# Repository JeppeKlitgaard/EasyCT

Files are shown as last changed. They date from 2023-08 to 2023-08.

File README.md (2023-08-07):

# EasyCT

## Terminology

- Burden Resistor: Also known as *sampling resistor*

## Supported Inputs

EasyCT supports most current-mode current transformers
(that is, current transformers without a built-in burden resistor).
These will have their outputs listed as currents (typically $\textrm{mA}$ or $\textrm{A}$),
__not__ voltages ($\textrm{mV, V}$) 

Additionally the PCB footprint has support for the following transformers:
- Three Terminal Jacks (known as TRS, AUX, XLR)
  - [YHDC-SCT013-000](https://www.poweruc.pl/collections/split-core-current-transformers2/products/split-core-current-transformer-sct013-rated-input-5a-100a)
- 2-Wire
  - PZCT10020 (generally PZCT-XXXXX, etc)
  - DLXQ26-XXXX
- ZMCT-style
  - ZMCT103C
  - ZMCT118F

## Supported Configurations

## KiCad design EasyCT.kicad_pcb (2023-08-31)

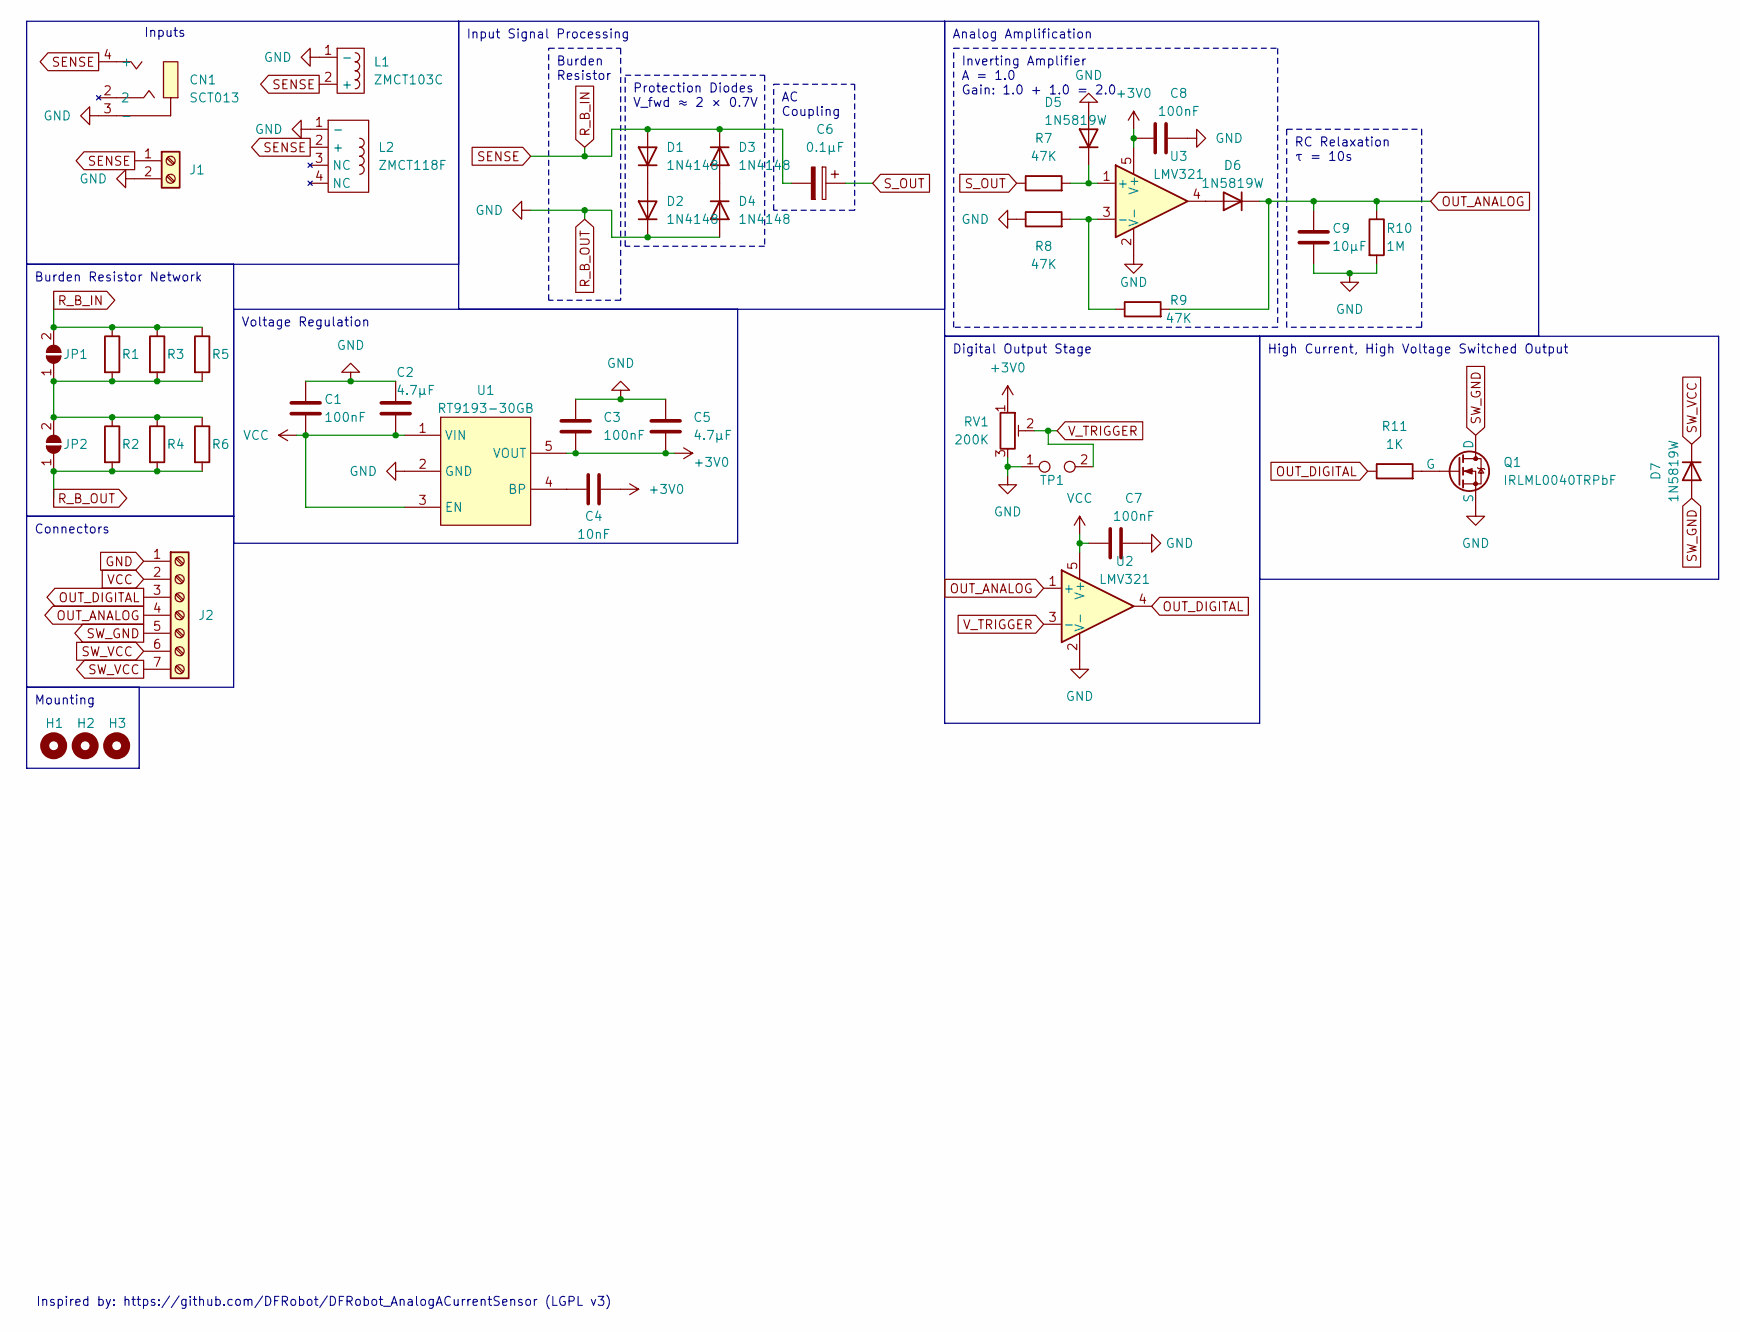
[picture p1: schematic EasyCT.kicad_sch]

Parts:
C1, C3, C7, C8: 100nF; C_0805_2012Metric
C2, C5: 4.7μF; C_0805_2012Metric
C4: 10nF; C_0805_2012Metric
C6: 0.1μF; C_0805_2012Metric
C9: 10μF; C_0805_2012Metric
CN1: SCT013; AUDIO-TH_HOOYA_PJ-320
D1, D2, D3, D4: 1N4148; D_SOD-123
D5, D6, D7: 1N5819W; D_SOD-323
H1, H2, H3: MountingHole; MountingHole_3.2mm_M3
J1: Screw_Terminal_01x02; CONN-TH_XY308-2.54-2P
J2: Screw_Terminal_01x07; CONN-TH_XY308-2.54-7P
JP1, JP2: SolderJumper_2_Open; SolderJumper-2_P1.3mm_Open_TrianglePad1.0x1.5mm
L1: ZMCT103C; Current_Transformer_CT_ZMCT103C
L2: ZMCT118F; XFMR-TH_ZMCT118F
Q1: IRLML0040TRPbF; SOT-23
R1, R2, R3, R4, R5, R6: R; R_Axial_DIN0207_L6.3mm_D2.5mm_P7.62mm_Horizontal
R7, R8, R9: 47K; R_0805_2012Metric
R10: 1M; R_0805_2012Metric
R11: 1K; R_0805_2012Metric
RV1: 200K; Potentiometer_Bourns_3296W_Vertical
TP1: TestPoint_2Pole; TestPoint_2Pads_Pitch5.08mm_Drill1.3mm
U1: RT9193-30GB; SOT-23-5_L3.0-W1.7-P0.95-LS2.8-BR; LCSC Part C50004
U2, U3: LMV321; SOT-23-5

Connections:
+3V0: C3.2, C4.1, C5.2, C8.1, RV1.1, U1.5 (VOUT), U3.5 (V+)
GND: C1.1, C2.1, C3.1, C5.1, C7.2, C8.2, C9.2, CN1.3 (-), D2.1 (K), D4.2 (A), D5.2 (A), J1.2, J2.1, JP2.1 (A), L1.1 (-), L2.1 (-), Q1.3 (S), R2.2, R4.2, R6.2, R8.1, R10.2, RV1.3, TP1.1, U1.2 (GND), U2.2 (V-), U3.2 (V-)
unnamed: D1.1 (K), D2.2 (A)
unnamed: D3.2 (A), D4.1 (K)
unnamed: D5.1 (K), R7.2, U3.1 (+)
unnamed: D6.2 (A), U3.4
unnamed: JP1.1 (A), JP2.2 (B), R1.2, R2.1, R3.2, R4.1, R5.2, R6.1
unnamed: Q1.2 (G), R11.2
unnamed: C4.2, U1.4 (BP)
unnamed: R8.2, R9.1, U3.3 (-)
OUT_ANALOG: C9.1, D6.1 (K), J2.4, R9.2, R10.1, U2.1 (+)
OUT_DIGITAL: J2.3, R11.1, U2.4
R_B_IN: C6.2, CN1.4 (+), D1.2 (A), D3.1 (K), J1.1, JP1.2 (B), L1.2 (+), L2.2 (+), R1.1, R3.1, R5.1
SW_GND: D7.2 (A), J2.5, Q1.1 (D)
SW_VCC: D7.1 (K), J2.6, J2.7
S_OUT: C6.1, R7.1
VCC: C1.2, C2.2, C7.1, J2.2, U1.1 (VIN), U1.3 (EN), U2.5 (V+)
V_TRIGGER: RV1.2, TP1.2, U2.3 (-)

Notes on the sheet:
Protection Diodes V_fwd ≈ 2 × 0.7V
RC Relaxation τ = 10s
Input Signal Processing
AC Coupling
Mounting
High Current, High Voltage Switched Output
Inverting Amplifier A = 1.0 Gain: 1.0 + 1.0 = 2.0
Burden Resistor Network
Analog Amplification
Burden Resistor
Digital Output Stage
Voltage Regulation
Connectors
Inputs
Inspired by: https://github.com/DFRobot/DFRobot_AnalogACurrentSensor (LGPL v3)

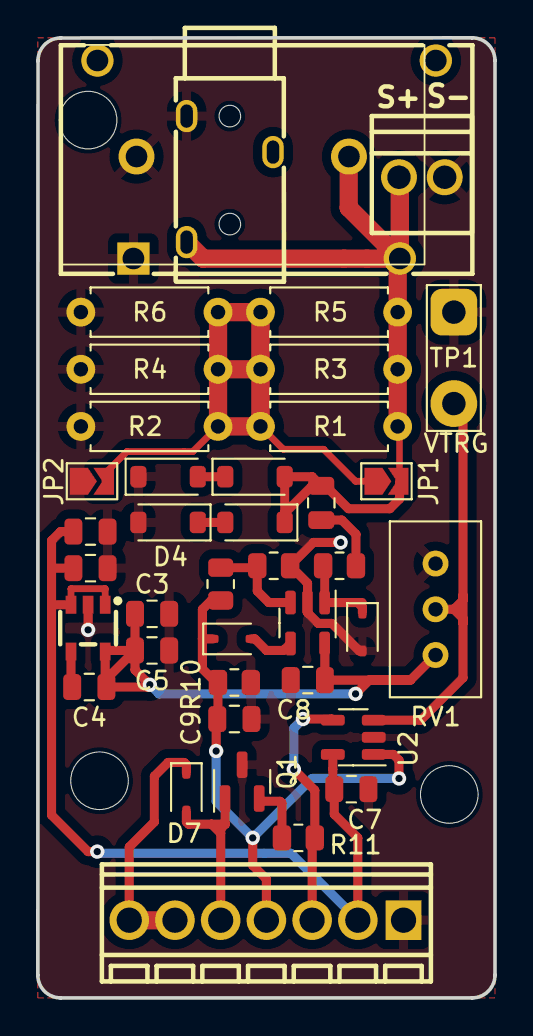
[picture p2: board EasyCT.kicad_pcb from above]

Board: 2 copper layers, 25.4 x 53.3 mm, 43 parts (0 on the bottom side), 18 nets.
